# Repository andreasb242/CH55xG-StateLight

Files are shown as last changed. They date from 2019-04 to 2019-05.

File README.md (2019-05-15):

# CH55xG-StateLight
CH552 / CH551 USB State Light

## Source Code
Tab size is 4 Spaces

## PC Software
Basically working on Linux, no Messenger sync yet

## Protocol
This is the Target protocol, not 100% ready.

>Sended Text

>$ Received Text

All Texts are are terminated with \n, \r or Both (don't matter)

Normal Sequence:
>i

>$TODO

Check if Version is correct.

Set all LEDs:
>aRRGGBB

>$OK

RRGGBB is an RGB Hex Color
This will turn off blink.

Set single LED:
>sID RRGGBB

>$OK

ID is the LED ID, starting from 0, decimal
RRGGBB is an RGB Hex Color
This will turn off blink.

Set auto off time after XXX Seconds
>aXXX

>$OK

If there is no command received within XXX Seconds, turn off LEDs

Ping:
>p

>$OK

Used to prevent auto turn off

Blink:
>tXXX

>$OK

Set blink time to TTT * 100ms
Defaults to 5, => 500ms blink time.

>b255

>$OK

Blink all LEDs

>bID

>$OK

Blink LED ID, ID is decimal

Write config byte:
>caaa vvv

>$OK

aaa Address: decimal, 0 .. 127
vvv Value: decimal, 0 .. 255

Read config byte:
>raaa

>$OK vvv

aaa Address: decimal, 0 .. 127
vvv Value: decimal, 0 .. 255

Write value to EEPROM

## EEPROM Config
0 - 1: USB VID
2 - 3: USB PID
4: '>' if USB ID SHould be readed

5 - 23: Startup RGB Colors, RRGGBB.
24: '>' if RGB Colors should be read

25 ... n: Serial, Terminated with double 0, FF are ignored

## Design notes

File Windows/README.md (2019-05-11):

# Powershell Controller for Windows
## Driver for Windows 7
For Windows 7 you need a driver, or you need to change to the VID:PID, to
a value which is known by Windows 7. Which is against USB Standard...
(e.g. the Microchip CDC Demo ID works, but do it at your own risk)

You can change it if you write it at the Beginning of the EEPROM, followed by a
">", see main Readme.

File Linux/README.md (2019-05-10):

# Linux Installation
## Install udev rule
To make sure the device has always the same name on Linux.

```
sudo cp 10-statelight.rules /etc/udev/rules.d/
```

## Install client
Copy statelight to your home, add statelight/statelight.py to autostart.

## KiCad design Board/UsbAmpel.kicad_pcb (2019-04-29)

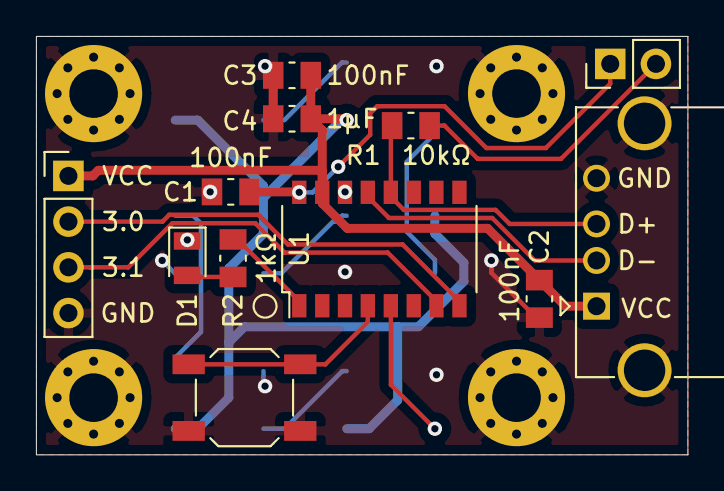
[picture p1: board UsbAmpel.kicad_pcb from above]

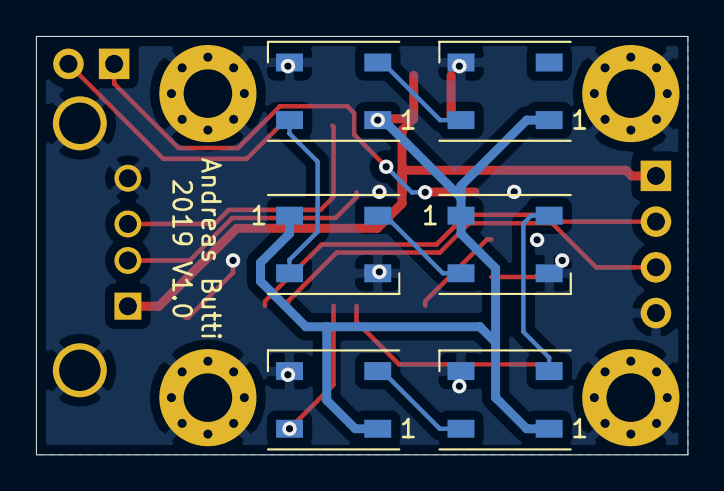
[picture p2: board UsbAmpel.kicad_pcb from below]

Board: 2 copper layers, 36.2 x 23.2 mm, 22 parts (6 on the bottom side), 17 nets.

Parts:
C1, C2, C3: 100nF; C_0805_2012Metric_Pad1.15x1.50mm_HandSolder
C4: 1µF; C_0805_2012Metric_Pad1.15x1.50mm_HandSolder
D1: LED; LED_0805_2012Metric_Pad0.97x1.50mm_HandSolder
D2, D3, D4, D5, D6, D7: WS2812B; LED_WS2812B_PLCC4_5.0x5.0mm_P3.2mm
J1: USB_A; USB_A_Horizontal
J2: Conn_01x02; PinHeader_1x02_P2.54mm_Vertical
J3: Conn_01x04; PinHeader_1x04_P2.54mm_Vertical
MK1, MK2, MK3, MK4: Mounting_Hole_PAD; MountingHole_2.7mm_M2.5_Pad_Via
R1: 10kΩ; R_0805_2012Metric_Pad1.15x1.50mm_HandSolder
R2: 1kΩ; R_0805_2012Metric_Pad1.15x1.50mm_HandSolder
SW1: SW_Push; SW_SPST_SKQG
U1: CH55xG; SOP-16_4.4x10.4mm_P1.27mm

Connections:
+3V3: C1.1, J2.1, U1.16
/BOOT: J2.2, R1.1
/D+: J1.3, R1.2, U1.12
/D-: J1.2, U1.13
/P1.6: SW1.1, U1.4
/P1.7: D2.4, U1.5
/P3.0: J3.2, U1.8
/P3.1: J3.3, U1.7
/P3.2: R2.2, U1.1
GND: C1.2, C2.2, C3.2, C4.2, D1.1, D2.3, D3.3, D4.3, D5.3, D6.3, D7.3, J1.4, J1.5, J3.4, MK1.1, MK2.1, MK3.1, MK4.1, SW1.2, U1.14
unnamed: D1.2, R2.1
unnamed: D2.2, D3.4
unnamed: D3.2, D4.4
unnamed: D4.2, D5.4
unnamed: D5.2, D6.4
unnamed: D6.2, D7.4
VCC: C2.1, C3.1, C4.1, D2.1, D3.1, D4.1, D5.1, D6.1, D7.1, J1.1, J3.1, U1.15

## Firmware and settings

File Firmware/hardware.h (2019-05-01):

/**
 * Hardware initialisation
 *
 * Andreas Butti, (c) 2019
 * License: GPL
 */

#pragma once

#include "inc.h"

// USB BUFFER -----------------------------------------------------------------

#undef DEFAULT_ENDP0_SIZE
#define DEFAULT_ENDP0_SIZE	64
#undef DEFAULT_ENDP1_SIZE
#define DEFAULT_ENDP1_SIZE	64

// Endpoint 0 OUT & IN buffer, must be an even address
extern __xdata __at (0x0000) uint8_t  Ep0Buffer[DEFAULT_ENDP0_SIZE];

// Endpoint 1 upload buffer
extern __xdata __at (0x0040) uint8_t  Ep1Buffer[DEFAULT_ENDP1_SIZE];

// Endpoint 2 IN & OUT buffer, must be an even address
extern __xdata __at (0x0080) uint8_t  Ep2Buffer[2 * MAX_PACKET_SIZE];

// ----------------------------------------------------------------------------


/**
 * USB device mode configuration
 */
void USBDeviceCfg();

/**
 * Enable USB Endpoint
 */
void USBDeviceEndPointCfg();

/**
 * USB device mode interrupt initialization
 */
void USBDeviceIntCfg();

/**
 * Print string to Serial 0
 */
void print(const char* str);

/**
 * This function provided a way to access the internal bootloader
 */
void jumpToBootloader();

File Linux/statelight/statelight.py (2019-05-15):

#!/usr/bin/python3

# State Light client
# License: GPL
# Author: Andreas Butti

import os
import signal
import gi
import json
import cairo
import serial
import dbus
from dbus.mainloop.glib import DBusGMainLoop

from collections import OrderedDict

gi.require_version('Gtk', '3.0')
gi.require_version('AppIndicator3', '0.1')

from gi.repository import Gtk as gtk
from gi.repository import Gdk as gdk
from gi.repository import AppIndicator3 as appindicator
from gi.repository import GObject

APPINDICATOR_ID = 'state-light'
lastIconId = 0
pidingSynEnabled = False
menuSyncPidgin = None


def statusChangedCallback(account, oldStatus, newStatus):
	if pidingSynEnabled:
		applyPidginStatus()


def applyPidginStatus():
	status = purple.PurpleSavedstatusGetCurrent()
	statusType = purple.PurpleSavedstatusGetType(status)
	statusId = purple.PurplePrimitiveGetIdFromType(statusType)
	statusText = purple.PurpleSavedstatusGetMessage(status)
	
	print("Status: " + statusId)
	print("  Text: " + statusText)

	mapping = config["pidgin"]["mapping"].get(statusId)
	if mapping == None:
		mapping = config["pidgin"]["mapping"].get("default")

	if mapping == None:
		# No default mapping
		return

	m = mapping.get(statusText)
	if m == None:
		m = mapping["*"]

	colorStr = m["color"]
	color = int(colorStr, 16)
	
	applyColor(color)


def main():
	global indicator
	global config
	global purple

	DBusGMainLoop(set_as_default=True)

	with open('config.json') as json_data_file:
		config = json.load(json_data_file, object_pairs_hook=OrderedDict)

	# Get pidgin D-BUS session
	if config["pidgin"]["enabled"]:
		purple = connectPidgin()
		print("Pidgin enabled");
	else:
		print("Pidgin disabled");
		purple = None

	indicator = appindicator.Indicator.new(APPINDICATOR_ID, os.path.abspath('statelight.svg'), appindicator.IndicatorCategory.SYSTEM_SERVICES)
	indicator.set_status(appindicator.IndicatorStatus.ACTIVE)
	indicator.set_menu(build_menu())
	
	if purple != None:
		pidingSynEnabled = True
		applyPidginStatus()

#	GObject.timeout_add(1000, updateTemperature)
	gtk.main()


def connectPidgin():
	bus = dbus.SessionBus()

	bus.add_signal_receiver(statusChangedCallback, dbus_interface="im.pidgin.purple.PurpleInterface", signal_name="AccountStatusChanged")
	obj = bus.get_object("im.pidgin.purple.PurpleService", "/im/pidgin/purple/PurpleObject")
	purple = dbus.Interface(obj, "im.pidgin.purple.PurpleInterface")

	return purple


def send_command(cmd):
	serialPort = serial.Serial("/dev/statelight", 9600, timeout=0.1)
	result = ""

	try:
		print("Send cmd: «" + cmd + "»")
		serialPort.write(cmd.encode())
		serialPort.flush()
		result = serialPort.readline().decode().strip()
		print("serial result: «" + result + "»")
	except BaseException as e:
		return False, "Exception " + str(e)

	try:
		serialPort.close()
	except BaseException as e:
		return False, "Exception " + str(e)

	return result == "OK", result


def applyColor(color):
	global lastIconId

	pixbuf = draw_icon(color, True)
	
	lastIconId = lastIconId + 1
	if lastIconId > 2:
		lastIconId = 0
	
	iconpath = "/tmp/StateLightIcon" + str(lastIconId) + ".png"
	pixbuf.savev(iconpath, "png", [], [])
	indicator.set_icon_full(iconpath, str(color))

	brightness = config["led"]["brightness"]
	colr = int(((color >> 16) & 0xff) / brightness)
	colg = int(((color >>  8) & 0xff) / brightness)
	colb = int(((color >>  0) & 0xff) / brightness)

	colorSend = colr << 16 | colg << 8 | colb

	cmd = "a" + ('%06x' % colorSend).upper() + "\n"
	ok, result = send_command(cmd)
	if ok == False:
		print("Send data failed with «" + result + "»")
	

def menucb_setColor(item, color):
	global pidingSynEnabled
	global menuSyncPidgin

	pidingSynEnabled = False
	menuSyncPidgin.set_active(False)
	applyColor(color)


def draw_icon(color, small = False):
	surface = cairo.ImageSurface(cairo.FORMAT_ARGB32, 16, 16)
	cr = cairo.Context(surface)

	colr = ((color >> 16) & 0xff) / 255.0
	colg = ((color >>  8) & 0xff) / 255.0
	colb = ((color >>  0) & 0xff) / 255.0
	cr.set_source_rgb(colr, colg, colb)

	if small:
		cr.rectangle(4, 4, 8, 8)
		cr.fill()
	else:
		cr.rectangle(0, 0, 16, 16)
		cr.fill()

	return gdk.pixbuf_get_from_surface(surface, 0, 0, 16, 16)


def menucb_syncPidginState(item):
	global pidingSynEnabled
	
	if pidingSynEnabled == menuSyncPidgin.get_active():
		print("Pidgin sync not changed")
		return

	pidingSynEnabled = menuSyncPidgin.get_active()
	print("Pidgin sync changed to " + str(pidingSynEnabled))

	if pidingSynEnabled:
		applyPidginStatus()


def build_menu():
	global menuSyncPidgin

	menu = gtk.Menu()

	states = config['states']
	for s in states:
		color = int(states[s], 16)

		menu_state = gtk.ImageMenuItem(s)
		menu_state.connect('activate', menucb_setColor, color)

		pixbuf = draw_icon(color)

		img = gtk.Image()
		img.set_from_pixbuf(pixbuf)
		menu_state.set_image(img)
		menu_state.set_always_show_image(True)
		menu.append(menu_state)

	if purple != None:
		menu.append(gtk.SeparatorMenuItem())
		
		menuSyncPidgin = gtk.CheckMenuItem("Sync Pidgin State")
		menuSyncPidgin.set_active(True)
		menuSyncPidgin.connect('activate', menucb_syncPidginState)
		menu.append(menuSyncPidgin)

	menu.append(gtk.SeparatorMenuItem())

	item_quit = gtk.MenuItem('Quit')
	item_quit.connect('activate', quit)
	menu.append(item_quit)


	menu.show_all()
	return menu


def quit(_):
	gtk.main_quit()


if __name__ == "__main__":
	signal.signal(signal.SIGINT, signal.SIG_DFL)
	main()

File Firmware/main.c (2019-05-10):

/**
 * USB CDC controlled W2812b LEDs
 *
 * Andreas Butti, (c) 2019
 * License: GPL
 */

#include "inc.h"
#include "hardware.h"
#include "bitbang.h"
#include "logic.h"
#include "usb-cdc.h"
#include "timer.h"

/**
 * Interrupt needs to be here in the Main file
 * else it simple won't be called.
 */
void DeviceInterrupt(void) __interrupt(INT_NO_USB) {
	usbInterrupt();
}


/**
 * Timer 0 interrupt
 */
void timer0() __interrupt(INT_NO_TMR0) {
	timer0clock();
}


/**
 * Firmware main
 */
void main() {
	// CH55x clock selection configuration
	CfgFsys();

	// Modify the main frequency and wait for the internal crystal to stabilize.
	mDelaymS(5);

	// Serial port 0, can be used for debugging
	mInitSTDIO();

	PRINT_DBG("UART init");

	// Initialize timer
	timerSetup();

	loadColorsFromEeprom();

    bitbangSetup();
    updateLeds();

	PRINT_DBG("bitbangSetup");

	// Enable USB Port
	USBDeviceCfg();

	PRINT_DBG("USBDeviceCfg");

	// Endpoint configuration
	USBDeviceEndPointCfg();

	PRINT_DBG("USBDeviceEndPointCfg");

	// Interrupt initialization
	USBDeviceIntCfg();

	PRINT_DBG("USBDeviceIntCfg");

	UEP0_T_LEN = 0;

	// Pre-use send length must be cleared
	UEP1_T_LEN = 0;

	// Pre-use send length must be cleared
	UEP2_T_LEN = 0;

	// Main Loop
	while(1) {
		PRINT_DBG("l");

	    P3_2 = 1;
		UsbCdc_processOutput();
	    P3_2 = 0;

		UsbCdc_processInput();

		logicLoop();
	}
}

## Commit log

2019-04-29 Initial import
    [UsbAmpel-B_Cu.gbr, UsbAmpel-B_Mask.gbr, UsbAmpel-B_Paste.gbr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]
2019-05-01 USB to UART forwarding working (Test)
2019-05-01 Removed I2C
2019-05-01 LEDs on the correct pin
    [bitbang.c]
2019-05-01 LED Control working over USB
2019-05-04 Last fixes - current date as serial number
2019-05-10 EEProm
    -Small fixed
    -Reading / Writing Eeprom scripts
    [eeprom_read.py, eeprom_write.py, statelight.py]
2019-05-10 Loading VID / PID from EEPROM working
2019-05-11 Setting Color to device is working
2019-05-12 Timer working
2019-05-27 Add timeout for write, fix random issues
    [eeprom_write.py]
2019-05-30 If the device is reconnected, send color again
2019-06-21 Handle turn off LEDs on USB Standby
